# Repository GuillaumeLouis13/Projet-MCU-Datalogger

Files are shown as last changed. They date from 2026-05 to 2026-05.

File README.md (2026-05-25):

📊 Datalogger MCU Embarqué

Projet créé dans le cadre d'une formation en conception électronique sous KiCad. Ce datalogger est conçu pour enregistrer des données horodatées grâce à une horloge temps réel (RTC) et une mémoire non-volatile (EEPROM).

💡 Description du projet

J'ai réalisé ce projet en complément de mon stage pour approfondir mes compétences en routage PCB et en conception de systèmes embarqués. Le système repose sur un microcontrôleur ATmega328P et intègre les périphériques suivants :
- Microcontrôleur : ATmega328P-AU (Architecture AVR 8-bit), importé sur KiCad depuis une bibliothèque externe.
- Stockage : Mémoire EEPROM I2C (24LC1025) pour la journalisation des données.
- Horloge : RTC (DS1337S) avec sauvegarde pour le suivi temporel, importé sur KiCad depuis une bibliothèque externe.
- Interface : Connecteur ICSP pour la programmation et connecteurs dédiés (I2C, UART, GPIO) pour l'extension.

🛠️ Architecture électronique

Le circuit a été conçu avec une attention particulière sur la gestion du bruit et l'intégrité du signal :
- Routage 2 couches : Utilisation d'un plan de masse solide pour minimiser les interférences électromagnétiques.
- Découplage : Condensateurs placés au plus près des broches d'alimentation du MCU.
- Signalisation : Isolation des lignes sensibles (Quartz 16 MHz) et gestion rigoureuse du bus I2C.

📸 Aperçu du projet

Schema électrique : 

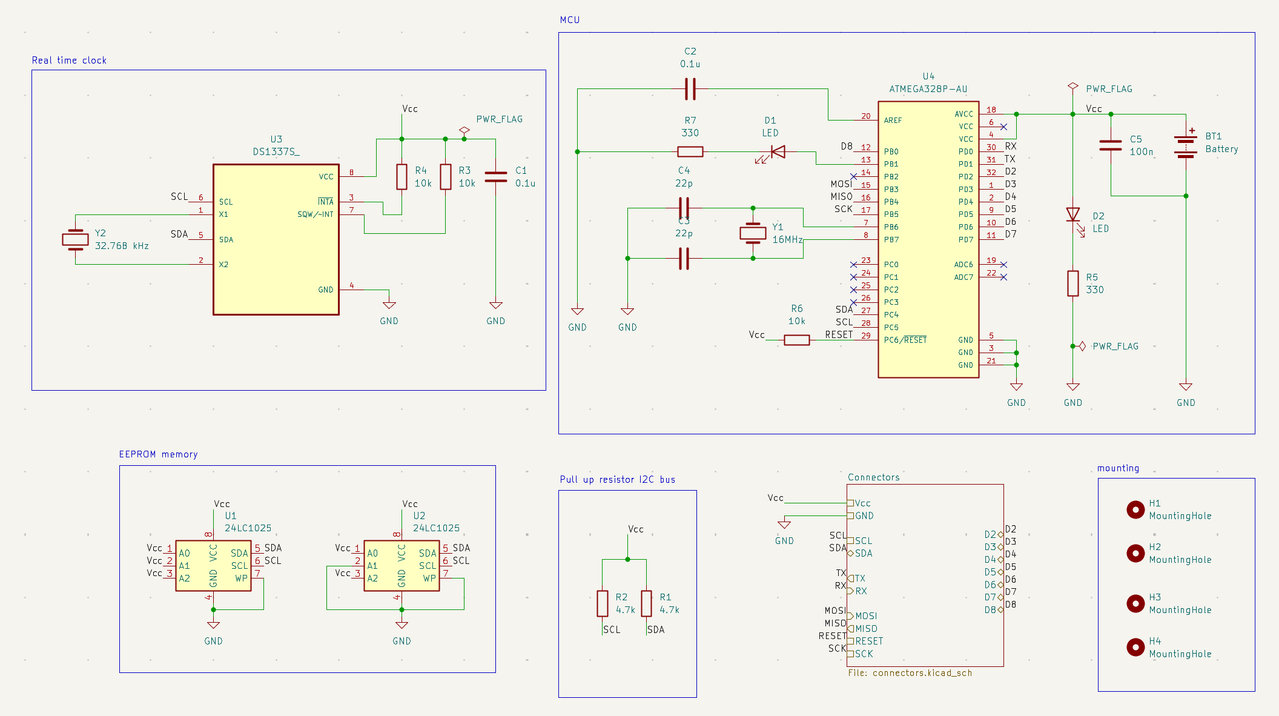
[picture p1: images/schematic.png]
Schema électrique


Routage PCB : 

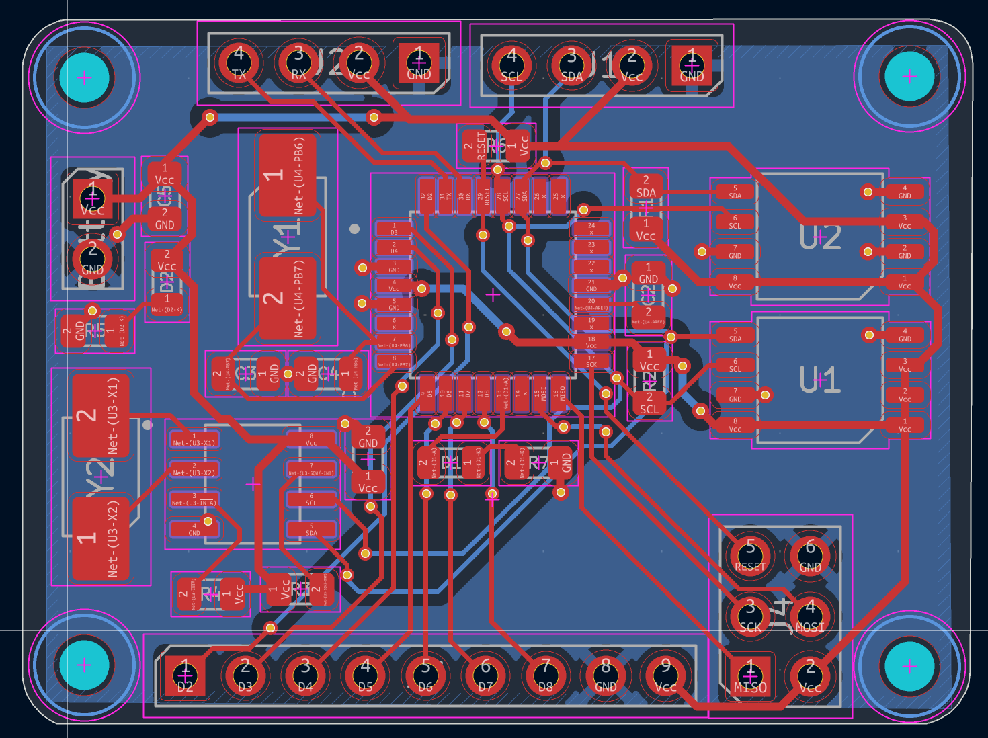
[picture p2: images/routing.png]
Routage PCB


Modèle 3D final : 

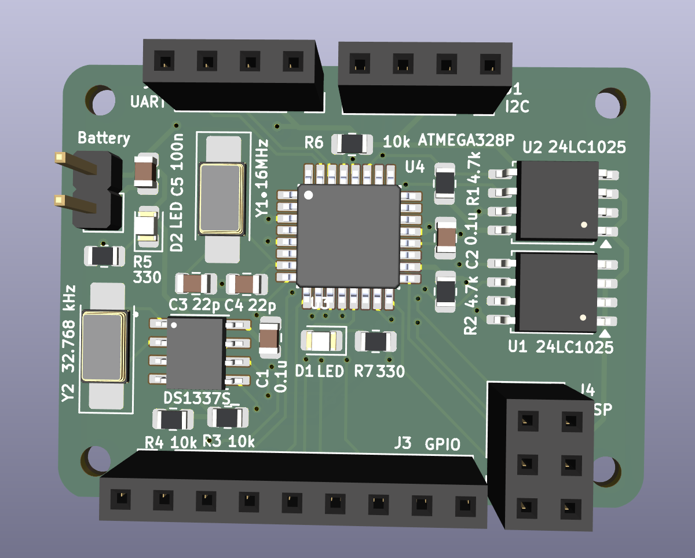
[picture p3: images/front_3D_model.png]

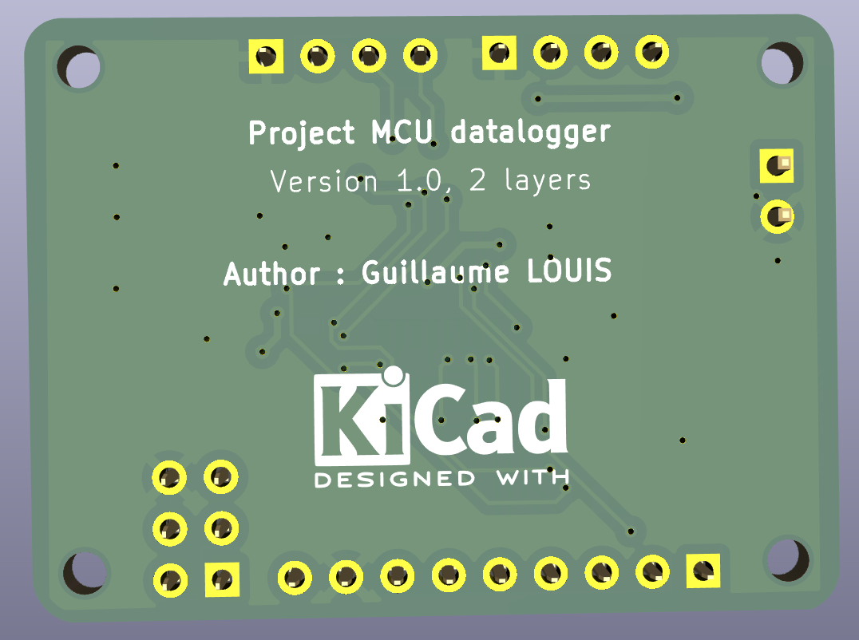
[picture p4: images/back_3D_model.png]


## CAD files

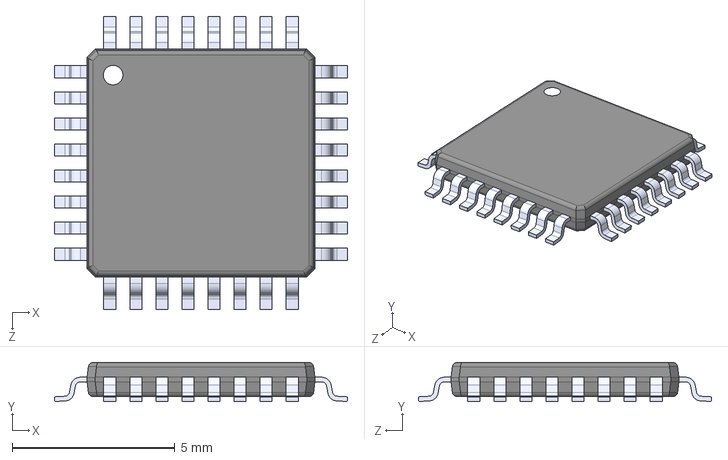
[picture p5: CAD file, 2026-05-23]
components libraries/ATMEGA328P-AU/ATMEGA328P-AU.step
9.00 x 1.20 x 9.00 mm

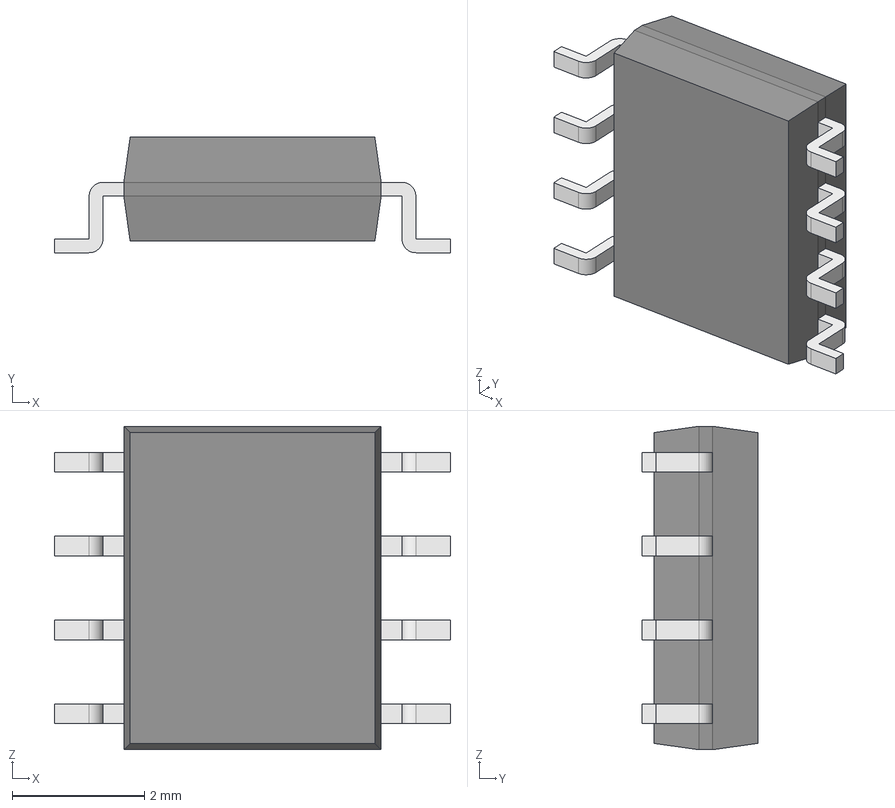
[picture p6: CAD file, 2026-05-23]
components libraries/DS1337S_/DS1337S_.step
6.00 x 1.75 x 4.90 mm
Body001 (Mirror #1) x 4
XY-plane x 12
X-axis x 12

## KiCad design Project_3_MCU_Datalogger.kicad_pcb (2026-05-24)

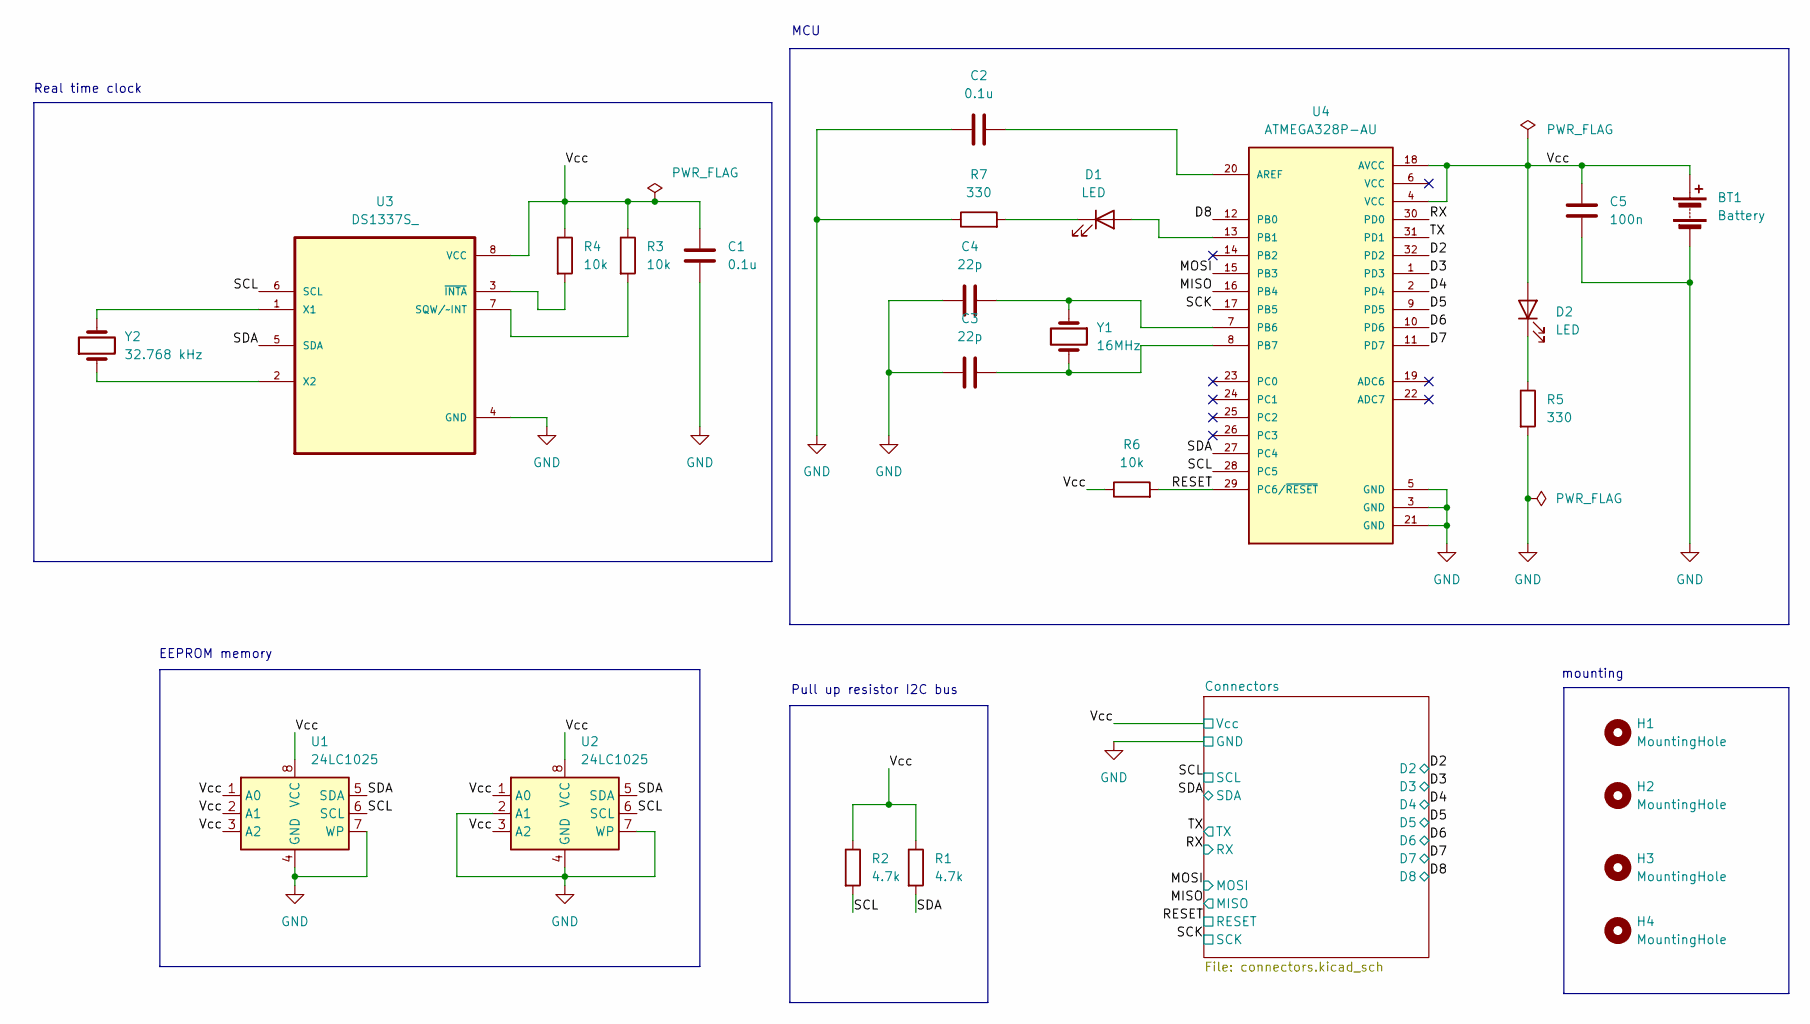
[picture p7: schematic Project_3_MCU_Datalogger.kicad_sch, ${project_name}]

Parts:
BT1: Battery; PinHeader_1x02_P2.54mm_Vertical
C1, C2: 0.1u; C_0805_2012Metric
C3, C4: 22p; C_0805_2012Metric
C5: 100n; C_0805_2012Metric
D1, D2: LED; LED_0805_2012Metric
H1, H2, H3, H4: MountingHole; MountingHole_2.1mm
R1, R2: 4.7k; R_0805_2012Metric
R3, R4, R6: 10k; R_0805_2012Metric
R5, R7: 330; R_0805_2012Metric
U1, U2: 24LC1025; SOIC-8_5.3x5.3mm_P1.27mm
U3: DS1337S_; SOIC127P600X175-8N
U4: ATMEGA328P-AU; QFP80P900X900X120-32N; PARTREV 8271A
Y1: 16MHz; Crystal_SMD_5032-2Pin_5.0x3.2mm_HandSoldering
Y2: 32.768 kHz; Crystal_SMD_5032-2Pin_5.0x3.2mm_HandSoldering

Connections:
/D2: U4.32 (PD2); also elsewhere on the board
/D3: U4.1 (PD3); also elsewhere on the board
/D4: U4.2 (PD4); also elsewhere on the board
/D5: U4.9 (PD5); also elsewhere on the board
/D6: U4.10 (PD6); also elsewhere on the board
/D7: U4.11 (PD7); also elsewhere on the board
/D8: U4.12 (PB0); also elsewhere on the board
/MISO: U4.16 (PB4); also elsewhere on the board
/MOSI: U4.15 (PB3); also elsewhere on the board
/RESET: R6.2, U4.29 (PC6/~RESET); also elsewhere on the board
/RX: U4.30 (PD0); also elsewhere on the board
/SCK: U4.17 (PB5); also elsewhere on the board
/SCL: R2.2, U1.6 (SCL), U2.6 (SCL), U3.6 (SCL), U4.28 (PC5); also elsewhere on the board
/SDA: R1.2, U1.5 (SDA), U2.5 (SDA), U3.5 (SDA), U4.27 (PC4); also elsewhere on the board
/TX: U4.31 (PD1); also elsewhere on the board
/Vcc: BT1.1 (+), C1.1, C5.1, D2.2 (A), R1.1, R2.1, R3.1, R4.1, R6.1, U1.1 (A0), U1.2 (A1), U1.3 (A2), U1.8 (VCC), U2.1 (A0), U2.3 (A2), U2.8 (VCC), U3.8 (VCC), U4.4 (VCC), U4.18 (AVCC); also elsewhere on the board
GND: BT1.2 (-), C1.2, C2.1, C3.1, C4.2, C5.2, R5.2, R7.1, U1.4 (GND), U1.7 (WP), U2.2 (A1), U2.4 (GND), U2.7 (WP), U3.4 (GND), U4.3 (GND), U4.5 (GND), U4.21 (GND); also elsewhere on the board
unnamed: D1.2 (A), U4.13 (PB1)
unnamed: D1.1 (K), R7.2
unnamed: D2.1 (K), R5.1
unnamed: R3.2, U3.7 (SQW/~INT)
unnamed: U3.1 (X1), Y2.2
unnamed: U3.2 (X2), Y2.1
unnamed: R4.2, U3.3 (~INTA)
unnamed: C2.2, U4.20 (AREF)
unnamed: C4.1, U4.7 (PB6), Y1.1
unnamed: C3.2, U4.8 (PB7), Y1.2

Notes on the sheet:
Pull up resistor I2C bus
MCU
Real time clock
mounting
EEPROM memory

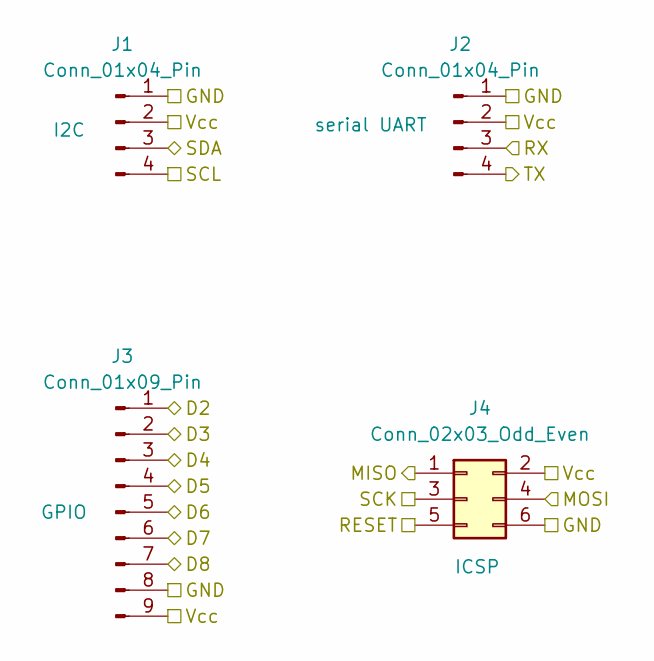
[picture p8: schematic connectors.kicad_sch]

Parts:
J1, J2: Conn_01x04_Pin; PinSocket_1x04_P2.54mm_Vertical
J3: Conn_01x09_Pin; PinSocket_1x09_P2.54mm_Vertical
J4: Conn_02x03_Odd_Even; PinSocket_2x03_P2.54mm_Vertical

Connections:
/D2: J3.1; also elsewhere on the board
/D3: J3.2; also elsewhere on the board
/D4: J3.3; also elsewhere on the board
/D5: J3.4; also elsewhere on the board
/D6: J3.5; also elsewhere on the board
/D7: J3.6; also elsewhere on the board
/D8: J3.7; also elsewhere on the board
/MISO: J4.1; also elsewhere on the board
/MOSI: J4.4; also elsewhere on the board
/RESET: J4.5; also elsewhere on the board
/RX: J2.3; also elsewhere on the board
/SCK: J4.3; also elsewhere on the board
/SCL: J1.4; also elsewhere on the board
/SDA: J1.3; also elsewhere on the board
/TX: J2.4; also elsewhere on the board
/Vcc: J1.2, J2.2, J3.9, J4.2; also elsewhere on the board
GND: J1.1, J2.1, J3.8, J4.6; also elsewhere on the board

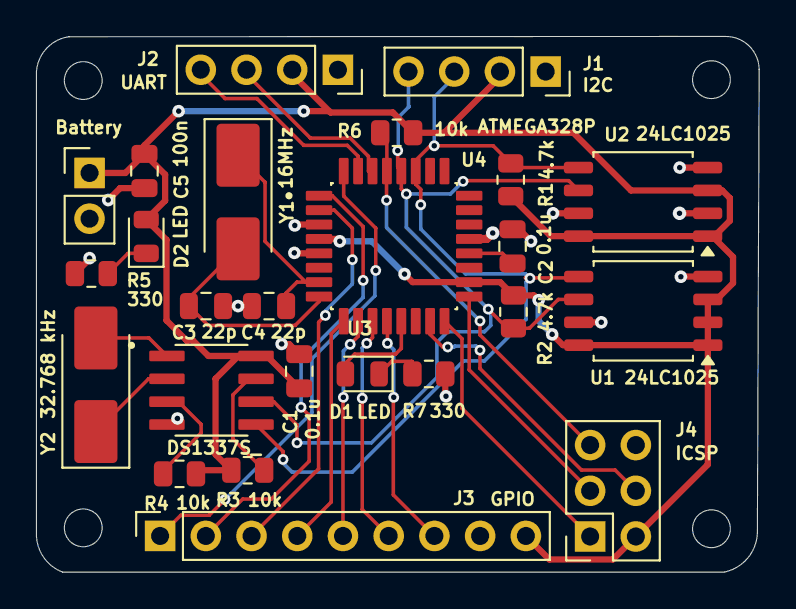
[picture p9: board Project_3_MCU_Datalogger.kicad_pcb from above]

Board: 2 copper layers, 40.2 x 29.8 mm, 29 parts (0 on the bottom side), 27 nets.

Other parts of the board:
Battery: Battery; PinHeader_1x02_P2.54mm_Vertical

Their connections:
/Vcc: Battery.1 (+); also elsewhere on the board
GND: Battery.2 (-); also elsewhere on the board

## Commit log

2026-05-23 Initial commit : Ajout du projet MCU datalogger KiCad
    [Project_3_MCU_Datalogger.kicad_pcb, Project_3_MCU_Datalogger.kicad_sch]
2026-05-23 Setup of EEschema for MCU project
    [Project_3_MCU_Datalogger.kicad_sch]
2026-05-23 Fix: ignore les fichiers de verrouillage KiCad
2026-05-23 ajout des symboles sur le schéma électrique + import de composants supplémentaires
    [Project_3_MCU_Datalogger.kicad_pcb, Project_3_MCU_Datalogger.kicad_sch, connectors.kicad_sch]
2026-05-23 stockage des libraries
    [ATMEGA328P-AU.step, DS1337S_.step, Project_3_MCU_Datalogger.kicad_sch]
2026-05-23 Change locations of the components
    [Project_3_MCU_Datalogger.kicad_sch]
2026-05-23 ajout des valeurs de composants
    [Project_3_MCU_Datalogger.kicad_sch]
2026-05-23 Association des empreintes aux composants
    [Project_3_MCU_Datalogger.kicad_sch, connectors.kicad_sch]
2026-05-23 wiring of sheet 1
    [Project_3_MCU_Datalogger.kicad_sch]
2026-05-23 wiring sheet 2, wiring done
    [Project_3_MCU_Datalogger.kicad_sch, connectors.kicad_sch]
2026-05-23 Gesstion des nets classes
2026-05-23 gestion de deux erreurs de footprint librairies
2026-05-23 encadrement des blocs et présentation du circuit
    [Project_3_MCU_Datalogger.kicad_sch]
2026-05-23 setup feuille PCB et importation 3D models
    [Project_3_MCU_Datalogger.kicad_pcb]
2026-05-23 Placement des composants avant routage
    [Project_3_MCU_Datalogger.kicad_pcb]
2026-05-24 amelioration disposition composants et changements circuit
    [Project_3_MCU_Datalogger.kicad_pcb, Project_3_MCU_Datalogger.kicad_sch]
2026-05-24 Fin du routage sur deux couches et modifications du schema
    [Project_3_MCU_Datalogger.kicad_pcb, Project_3_MCU_Datalogger.kicad_sch, connectors.kicad_sch]
2026-05-24 ajout des images du projet
2026-05-24 commit final version 2 layers
    [Project_3_MCU_Datalogger.kicad_pcb]
